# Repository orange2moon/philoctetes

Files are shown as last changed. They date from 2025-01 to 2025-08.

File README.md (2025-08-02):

# Philoctetes Keyboard

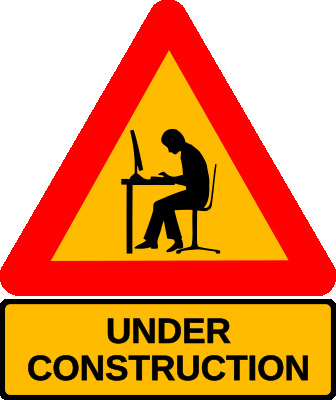
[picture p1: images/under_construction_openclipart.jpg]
Under Construction


## About this project

I have worked on this project for about 3 months. It is quite enjoyable, but also time consuming. I made two working keyboards, one bluetooth and one wireless. The feel of the layout is fantastic! Even if my keyboards are working, it's not ready for other people to build. I hope to have time to continue this project, but I can't make promises to anyone. I am sharing this repository for people who might be curious, and to give ideas so as to inspire people to make awesome keyboards.

__Design goals__  
In [congnitive load theory](https://practicalpie.com/cognitive-load-theory/) there are three processes. These are the intrinsic, the extrinsic, and the germane. The effort put into typing on a keyboard is purely extrinsic. So one day I had an idea, "could I reduce the extrinsic load of typing on a computer by changing my keyboard?". I think the answer is yes. As a result of this idea, my design goals gravitated toward 42 keys that are arranged to match my hand and the movements of my fingers.

This keyboard turned into a very expensive build. It is probably one of the most expensive split keyboards you can build. In addition I only considered the shape and size of my own hand when designing it. Please don't build it.

## Other Projects to Check Out

The [Totem](https://github.com/GEIGEIGEIST/TOTEM) keyboard. The Totem was the inspiration for this keyboard. I have huge respect for the creator of this project. The creator really put a lot of effort into making a great finished project.

I created this project with a different design goal in mind. The design goals of the Totem seem to be a portable and relativly low cost keyboard. In contrast, my design goals are to fit perfectly my own hand.

In addition, a big thanks to the [EIGA](https://www.youtube.com/@EIGAtech) youtube channel. Without their channel I would not have learned about the Totem and other split keyboards.

## To Do

__Case__  
[x] Add a case mount point to the far outside.  
[x] Add more space for the oled (the oled is not centered and it hits the lip holding the cover). Moving the oled mount half a mm towards the edge should help.  
[x] Add more space for the microcontroller (about 1mm on the inner side should do).  
[x] Add a curve for the TRRS conector.  

__PCB Both Sides__  
[x] fix the annotations  
[] change the footprints from sod-323 to sod-123.  
    - The Kicad library footprints look too small for hand soldering.  
[] Update the footprints in the PCB builder.  
[] Redo diode placement  
[] Redo routing  
[] Improve the silkscreen placements.  
[x] Improve the placement of the oled display.  
[x] Add a case mount point to the far outside.  
[x] Add a pull down resistor to the right side.  
[x] Remove the extra diode on the left side.  
[x] Panelize the keyboard.  
[x] Check the column and row labels and makes sure they match.  
[x] Check the oled and nice!view pinouts.  
  
__Project In General__  
[] Create a bill of materials  
[] Create a build guide  
[] Test latest PCB  
  
## Case  
  
The case uses a tenting system that I have used for a year. It's not perfect, but every-time I think of switching to a different design I can't find justification. The advantage of my tenting system is that it is very stable and very adjustable. My tenting system is not portable, meaning it will probably bet messed up if you put it in a bag and ride the subway (been there, done that).  
  
The case was designed using onshape and you can find a link to it [here](https://cad.onshape.com/documents/5c5e04ae1784123d6189c14c/w/86f29d74e9109abb974cb649/e/b3c51a35815c88e0a251e0eb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)  

## Images
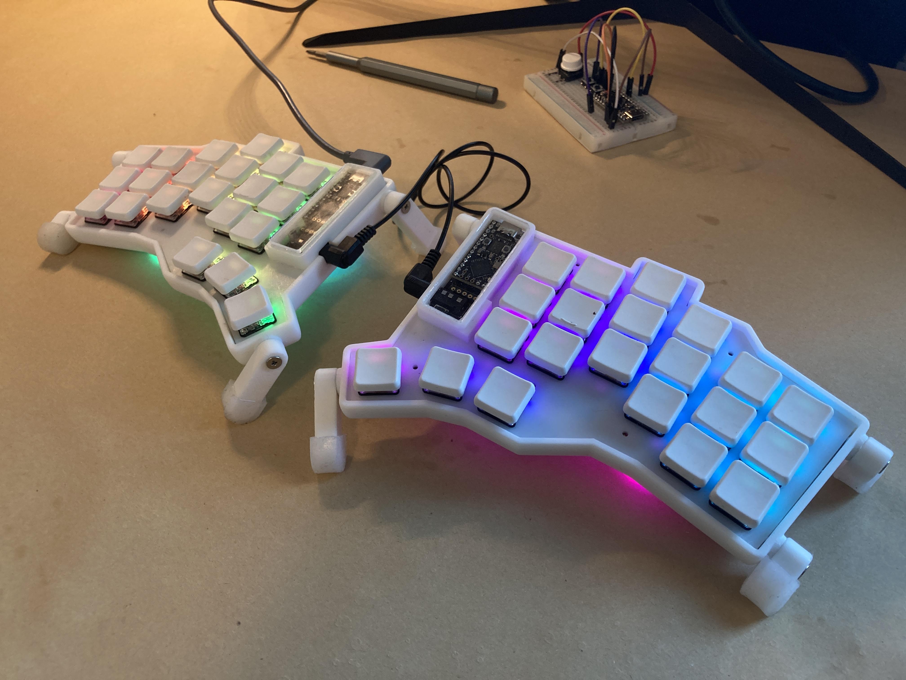
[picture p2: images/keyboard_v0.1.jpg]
Keyboard Version 0.1


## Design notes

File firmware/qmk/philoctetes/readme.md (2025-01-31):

# philoctetes

philoctetes

*A short description of the keyboard/project*

* Keyboard Maintainer: [orange2moon](https://github.com/orange2moon)
* Hardware Supported: *The PCBs, controllers supported*
* Hardware Availability: *Links to where you can find this hardware*

Make example for this keyboard (after setting up your build environment):

    make philoctetes:default

Flashing example for this keyboard:

    make philoctetes:default:flash

See the [build environment setup](https://docs.qmk.fm/#/getting_started_build_tools) and the [make instructions](https://docs.qmk.fm/#/getting_started_make_guide) for more information. Brand new to QMK? Start with our [Complete Newbs Guide](https://docs.qmk.fm/#/newbs).

## Bootloader

Enter the bootloader in 3 ways:

* **Bootmagic reset**: Hold down the key at (0,0) in the matrix (usually the top left key or Escape) and plug in the keyboard
* **Physical reset button**: Briefly press the button on the back of the PCB - some may have pads you must short instead
* **Keycode in layout**: Press the key mapped to `QK_BOOT` if it is available

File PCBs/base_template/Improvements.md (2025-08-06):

# Improvements

## Most important thing, ergonomics
- [x] adjust the ring finger column
    - It needs to come up a little
- [x] adjust the pinky finger column
    - the outer column needs to come up a little
    - the two pinky columns were moved outward a little

middle -> ring vertical space = 7.8 mm or 7.9 

## Mechanical improvements
- Change the footprints of the diodes
- [x] adjust the spacing of individual keys
    - The center is the middle finger, everything else moves around it

- Make room for a bigger battery
    - I could make a cutout under the mcu, this would give more
    clearance for a battery, also moving the display mount down would
    help a lot

## Things I wouldn't change
- The capacitors are great
    - add a bigger one, or two of the electrolytic capacitors, or one
    big through hole electrolytic and bend the wires over so it sits
    horizontally 

What is the spacing between keys vertically?
According to the corne project... it looks to be 19.05 mm 
This seems correct. The distance in my build was 18.13 and it seemed to
be about 1 mm or more too close.

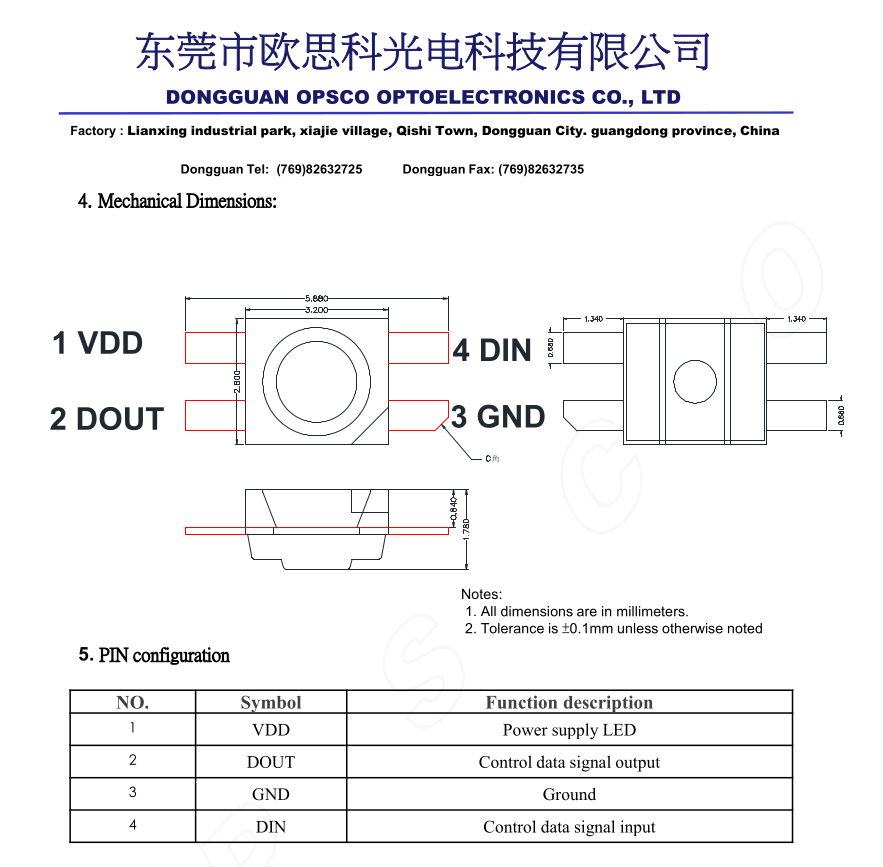
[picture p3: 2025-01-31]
bill_of_materials/data_sheet_ref/SK6812MINI-E_pinout.png

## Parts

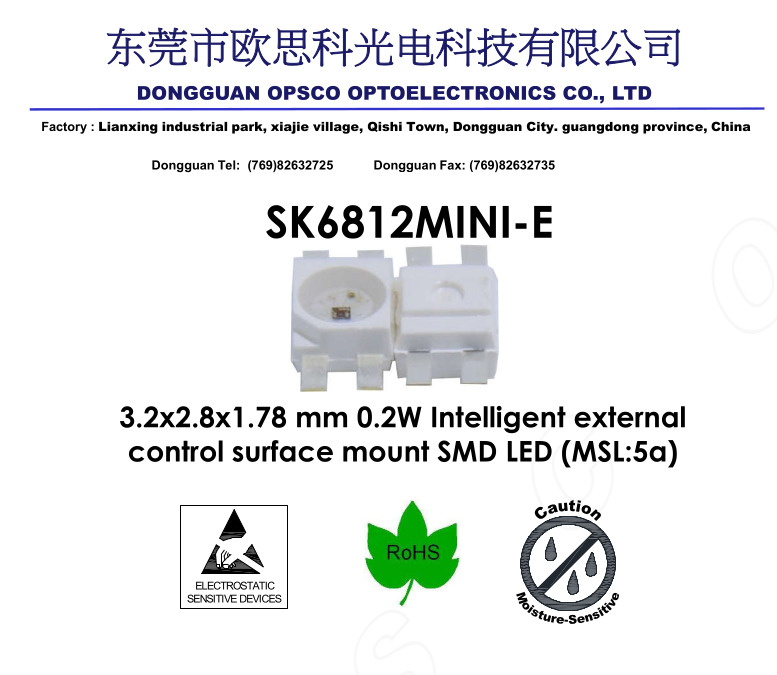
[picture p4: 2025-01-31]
bill_of_materials/data_sheet_ref/SK6812MINI-E.jpg

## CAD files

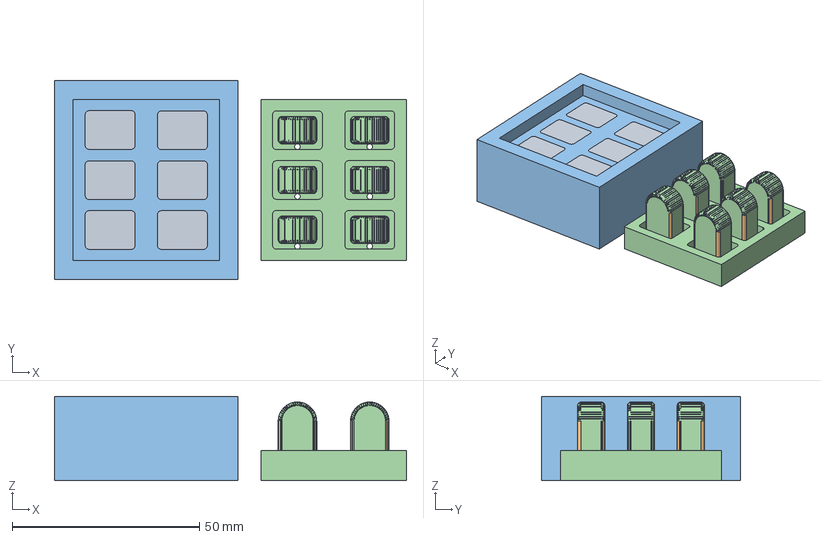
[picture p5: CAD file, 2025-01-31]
extras/silicone_mold_for_endcaps.FCStd
94.0 x 53.0 x 22.5 mm
base
mold_top
mold_bottom
mold_top (Meshed)001

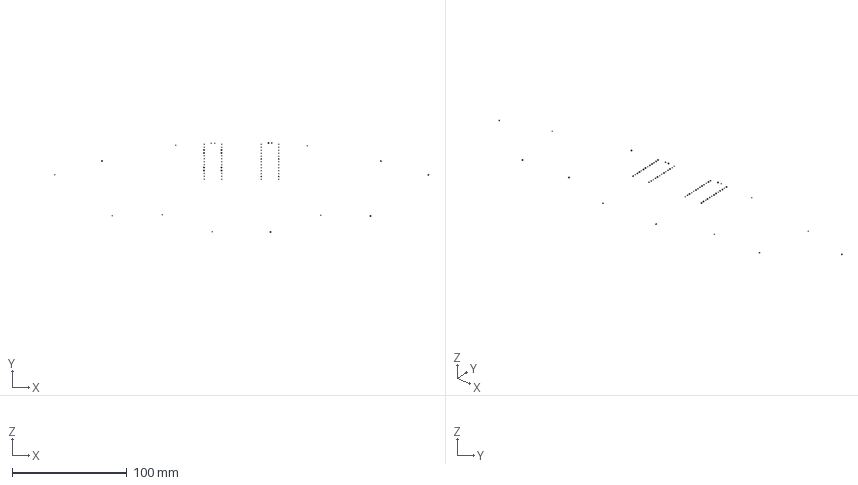
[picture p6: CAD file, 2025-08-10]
PCBs/base_template/layout/pcb_edges/pcb_edges_v3.FCStd
325.8 x 77.9 x 0 mm
circle714
circle715
circle716
circle717
circle718
circle719
circle720
circle721
circle722
circle723
circle724
circle725
circle726
circle727
circle728
circle729
circle730
circle731
circle732
circle733
circle734
circle735
circle736
circle737
circle738
circle739
circle740
circle747
circle760
circle761
circle762
circle763
circle778
circle779
circle816
circle825
circle838
circle839
circle869
circle870
circle871
circle872
circle879
circle880
circle881
circle882
circle883
circle884
circle885
circle886
circle887
circle888
circle889
circle890
circle891
circle892
circle893
circle894
circle895
circle896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

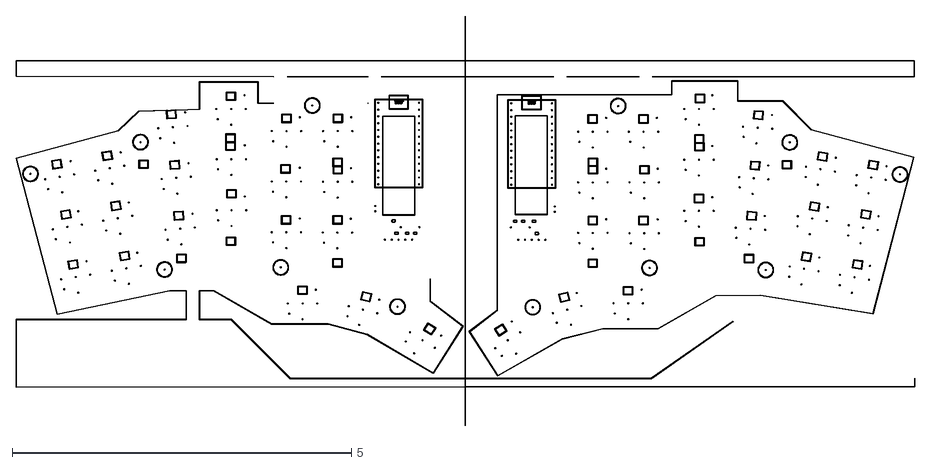
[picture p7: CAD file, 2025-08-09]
PCBs/base_template/layout/philoctetes-Edge_Cuts.dxf
13.2 x 6.03

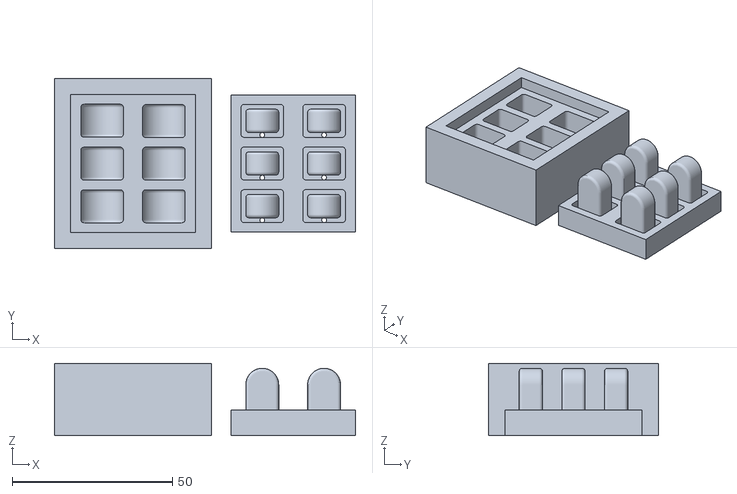
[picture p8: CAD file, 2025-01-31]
releases/V0.1/case/endcap_v3_all.stl
93.9 x 53.0 x 22.5

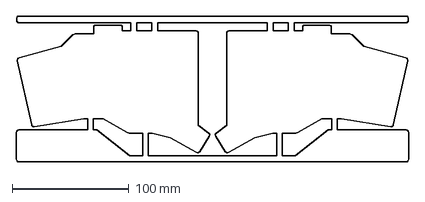
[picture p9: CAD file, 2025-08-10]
PCBs/base_template/layout/pcb_edges/pcb_edges_v3-BodySketch675.dxf
336.6 x 124.8 mm

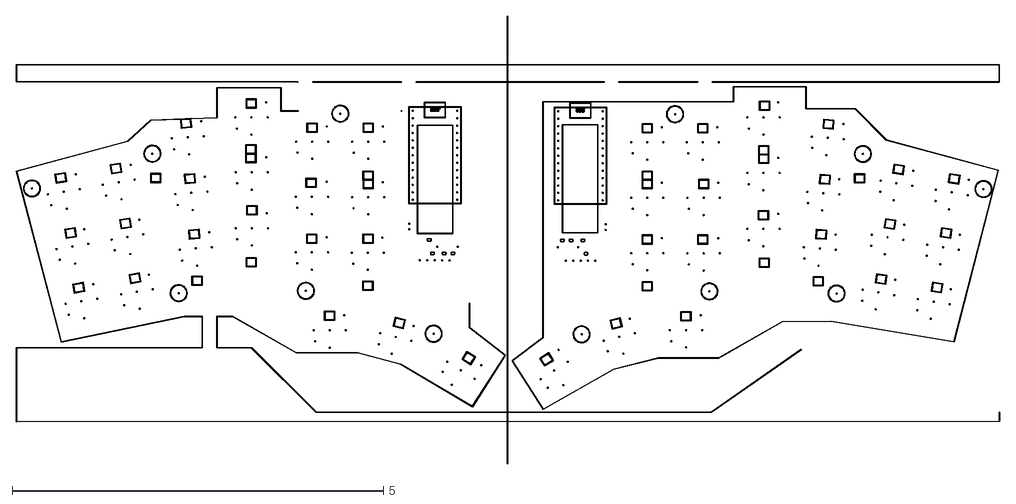
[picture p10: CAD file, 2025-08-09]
PCBs/base_template/layout/philoctetes-User_Comments.dxf
13.2 x 6.03

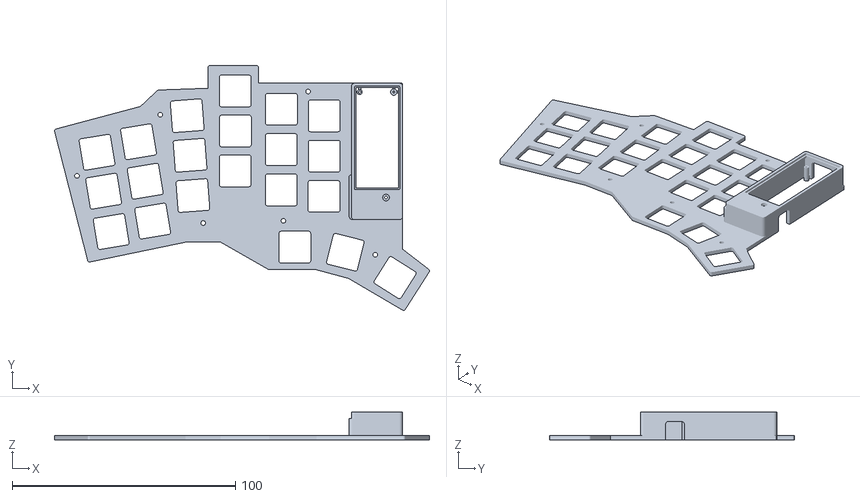
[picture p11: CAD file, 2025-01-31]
releases/V0.1/case/philoctetes_LEFT_top.stl
168.0 x 109.7 x 12.4

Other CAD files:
PCBs/base_template/edge_cuts/edge_cuts.FCStd
releases/V0.1/case/philoctetes_RIGHT_top.stl

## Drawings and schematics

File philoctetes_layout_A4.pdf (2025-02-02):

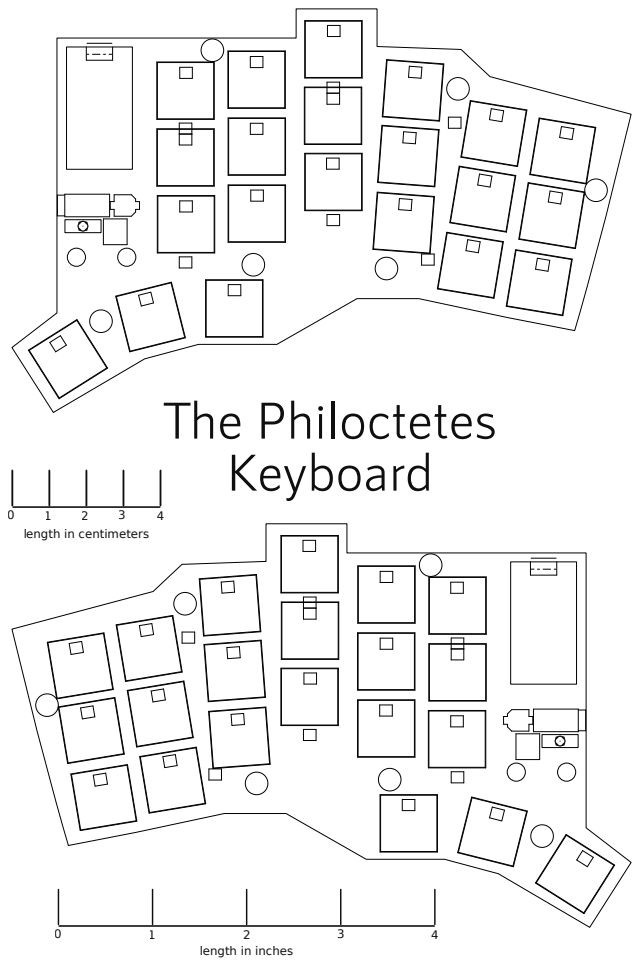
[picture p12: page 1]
The Philoctetes Keyboard

length in centimeters

length in inches

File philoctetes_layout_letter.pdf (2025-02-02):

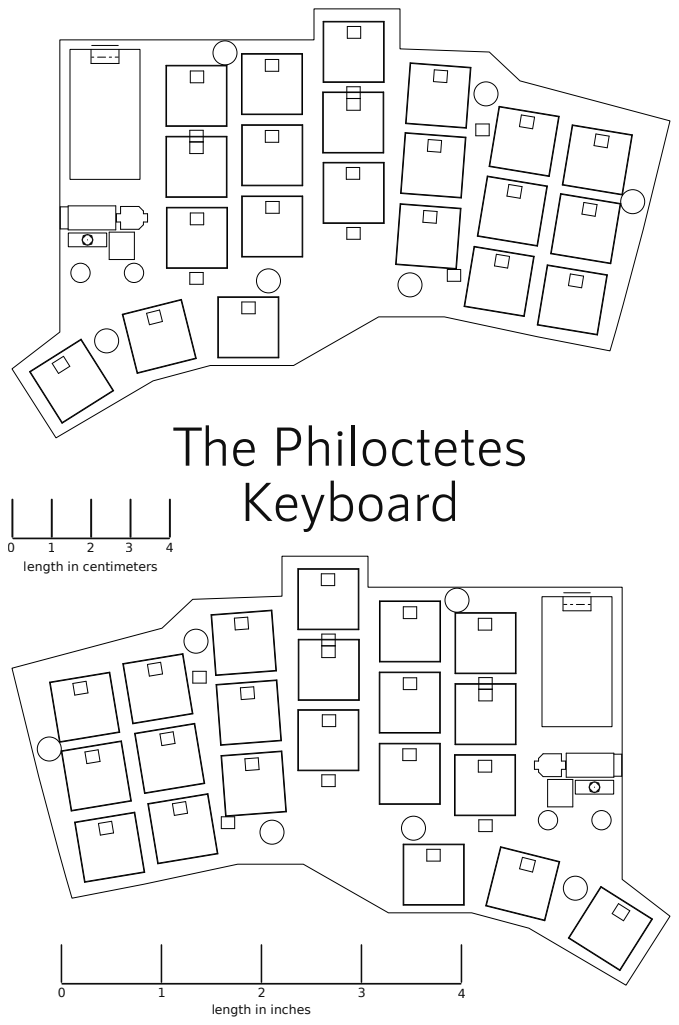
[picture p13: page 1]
The Philoctetes Keyboard

length in centimeters

length in inches

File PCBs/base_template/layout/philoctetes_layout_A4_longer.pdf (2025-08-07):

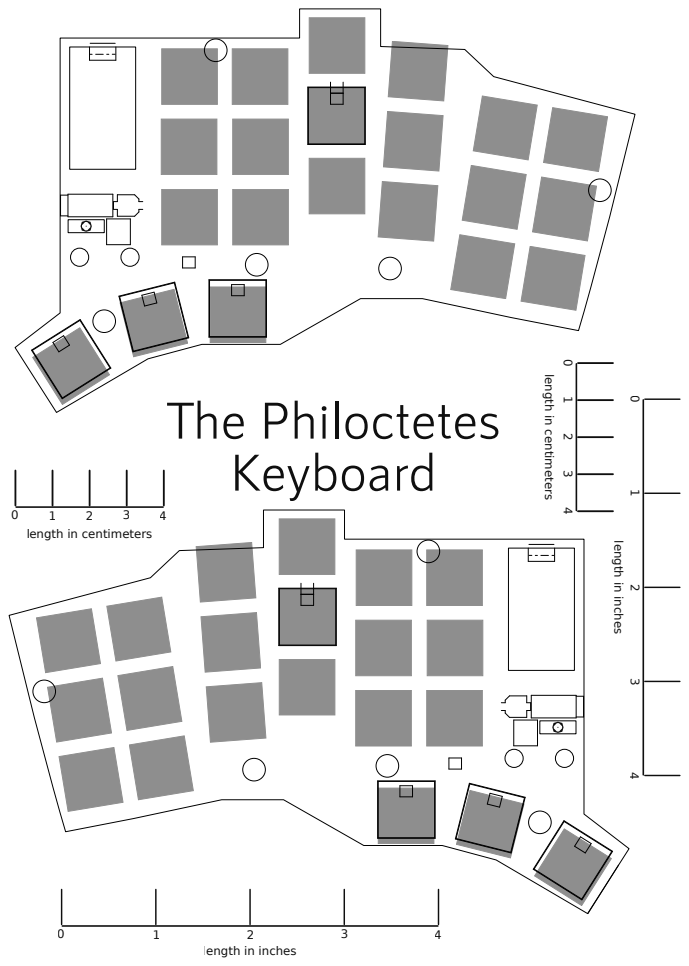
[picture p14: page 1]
The Philoctetes Keyboard

length in centimeters

length in inches

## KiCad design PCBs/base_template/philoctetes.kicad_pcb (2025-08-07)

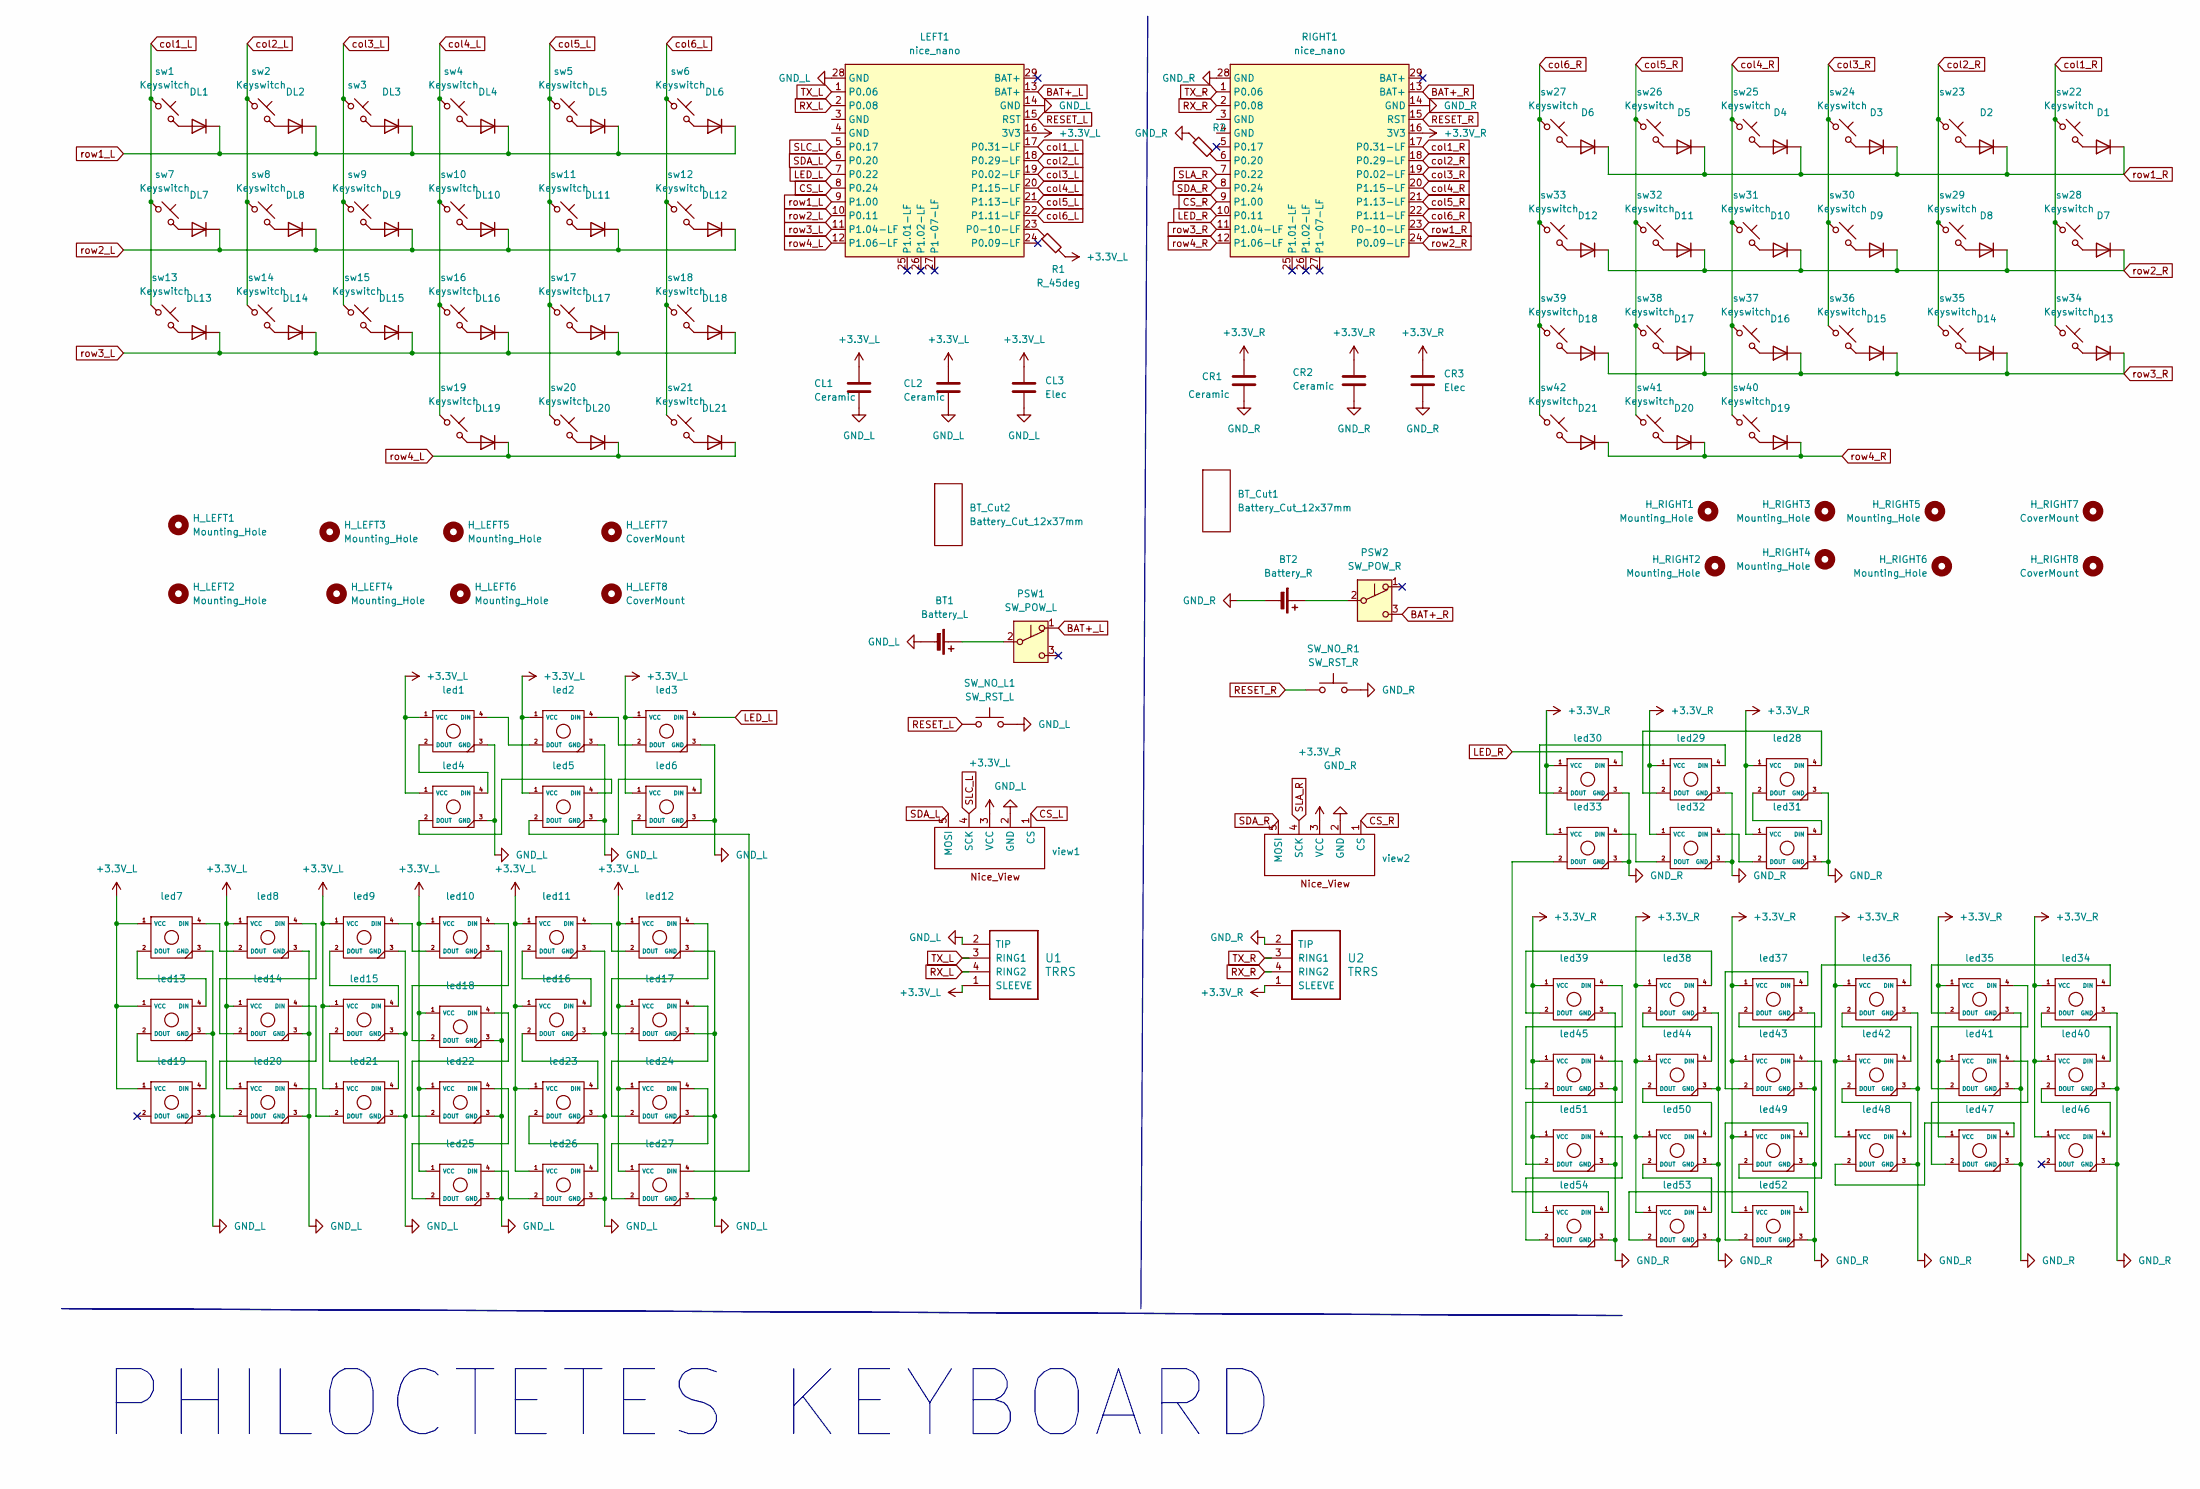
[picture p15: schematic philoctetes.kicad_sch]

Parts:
BT1: Battery_L; JST_GH_SM02B-GHS-TB_1x02-1MP_P1.25mm_Horizontal
BT2: Battery_R; JST_GH_SM02B-GHS-TB_1x02-1MP_P1.25mm_Horizontal
BT_Cut1, BT_Cut2: Battery_Cut_12x37mm
CL1, CL2: Ceramic; C_1206_3216Metric_Pad1.33x1.80mm_HandSolder
CL3: Elec; CP_Radial_D5.0mm_P2.00mm
CR1, CR2: Ceramic; C_1206_3216Metric_Pad1.33x1.80mm_HandSolder
CR3: Elec; CP_Radial_D5.0mm_P2.00mm
D1, D2, D3, D4, D5, D6, D7, D8, D9, D10, D11, D12, D13, D14, D15, D16, D17, D18, D19, D20, D21: 1N4148W; D_SOD-123F
DL1, DL2, DL3, DL4, DL5, DL6, DL7, DL8, DL9, DL10, DL11, DL12, DL13, DL14, DL15, DL16, DL17, DL18, DL19, DL20, DL21: 1N4148W; D_SOD-123F
H_LEFT1, H_LEFT2, H_LEFT3, H_LEFT4, H_LEFT5, H_LEFT6: Mounting_Hole; MountingHole_3.2mm_M3_DIN965
H_LEFT7, H_LEFT8: CoverMount; MountingHole_2.2mm_M2_Pad
H_RIGHT1, H_RIGHT2, H_RIGHT3, H_RIGHT4, H_RIGHT5, H_RIGHT6: Mounting_Hole; MountingHole_3.2mm_M3_DIN965
H_RIGHT7, H_RIGHT8: CoverMount; MountingHole_2.2mm_M2_Pad
LEFT1: nice_nano; nice_nano_AH_USBup
PSW1: SW_POW_L; MSK12C02
PSW2: SW_POW_R; MSK12C02
R1, R2: R_45deg; R_0805_2012Metric
RIGHT1: nice_nano; nice_nano_AH_USBup
SW_NO_L1: SW_RST_L; SW_RST
SW_NO_R1: SW_RST_R; SW_RST
U1, U2: TRRS; TRRS_PJ-320A
led1, led2, led3, led4, led5, led6, led28, led29, led30, led31, led32, led33: LED_SK6812MINI-E_faceup
led7, led8, led9, led10, led11, led12, led13, led14, led15, led16, led17, led18, led19, led20, led21, led22, led23, led24, led25, led26, led27, led34, led35, led36, led37, led38, led39, led40, led41, led42, led43, led44, led45, led46, led47, led48, led49, led50, led51, led52, led53, led54: LED_SK6812MINI-E_facedown
sw1, sw2, sw3, sw4, sw5, sw6, sw7, sw8, sw9, sw10, sw11, sw12, sw13, sw14, sw15, sw16, sw17, sw18, sw19, sw20, sw21, sw22, sw23, sw24, sw25, sw26, sw27, sw28, sw29, sw30, sw31, sw32, sw33, sw34, sw35, sw36, sw37, sw38, sw39, sw40, sw41, sw42: Keyswitch; Hotswap_Choc_V1V2_1.00u
view1, view2: nice_view

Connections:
+3.3V_L: CL1.1, CL2.1, CL3.1, LEFT1.16 (3V3), R1.2, U1.1 (SLEEVE), led1.1 (VCC), led2.1 (VCC), led3.1 (VCC), led4.1 (VCC), led5.1 (VCC), led6.1 (VCC), led7.1 (VCC), led8.1 (VCC), led9.1 (VCC), led10.1 (VCC), led11.1 (VCC), led12.1 (VCC), led13.1 (VCC), led14.1 (VCC), led15.1 (VCC), led16.1 (VCC), led17.1 (VCC), led18.1 (VCC), led19.1 (VCC), led20.1 (VCC), led21.1 (VCC), led22.1 (VCC), led23.1 (VCC), led24.1 (VCC), led25.1 (VCC), led26.1 (VCC), led27.1 (VCC), view1.3 (VCC)
+3.3V_R: CR1.1, CR2.1, CR3.1, RIGHT1.16 (3V3), U2.1 (SLEEVE), led28.1 (VCC), led29.1 (VCC), led30.1 (VCC), led31.1 (VCC), led32.1 (VCC), led33.1 (VCC), led34.1 (VCC), led35.1 (VCC), led36.1 (VCC), led37.1 (VCC), led38.1 (VCC), led39.1 (VCC), led40.1 (VCC), led41.1 (VCC), led42.1 (VCC), led43.1 (VCC), led44.1 (VCC), led45.1 (VCC), led46.1 (VCC), led47.1 (VCC), led48.1 (VCC), led49.1 (VCC), led50.1 (VCC), led51.1 (VCC), led52.1 (VCC), led53.1 (VCC), led54.1 (VCC), view2.3 (VCC)
BAT+_L: LEFT1.13 (BAT+), PSW1.1 (A)
BAT+_R: PSW2.3 (C), RIGHT1.13 (BAT+)
CS_L: LEFT1.8 (P0.24), view1.1 (CS)
CS_R: RIGHT1.9 (P1.00), view2.1 (CS)
GND_L: BT1.2 (-), CL1.2, CL2.2, CL3.2, LEFT1.14 (GND), LEFT1.28 (GND), SW_NO_L1.2, U1.2 (TIP), led1.3 (GND), led2.3 (GND), led3.3 (GND), led4.3 (GND), led5.3 (GND), led6.3 (GND), led7.3 (GND), led8.3 (GND), led9.3 (GND), led10.3 (GND), led11.3 (GND), led12.3 (GND), led13.3 (GND), led14.3 (GND), led15.3 (GND), led16.3 (GND), led17.3 (GND), led18.3 (GND), led19.3 (GND), led20.3 (GND), led21.3 (GND), led22.3 (GND), led23.3 (GND), led24.3 (GND), led25.3 (GND), led26.3 (GND), led27.3 (GND), view1.2 (GND)
GND_R: BT2.2 (-), CR1.2, CR2.2, CR3.2, R2.2, RIGHT1.14 (GND), RIGHT1.28 (GND), SW_NO_R1.2, U2.2 (TIP), led28.3 (GND), led29.3 (GND), led30.3 (GND), led31.3 (GND), led32.3 (GND), led33.3 (GND), led34.3 (GND), led35.3 (GND), led36.3 (GND), led37.3 (GND), led38.3 (GND), led39.3 (GND), led40.3 (GND), led41.3 (GND), led42.3 (GND), led43.3 (GND), led44.3 (GND), led45.3 (GND), led46.3 (GND), led47.3 (GND), led48.3 (GND), led49.3 (GND), led50.3 (GND), led51.3 (GND), led52.3 (GND), led53.3 (GND), led54.3 (GND), view2.2 (GND)
LED_L: LEFT1.7 (P0.22), led3.4 (DIN)
LED_R: RIGHT1.10 (P0.11), led30.4 (DIN)
unnamed: BT1.1 (+), PSW1.2 (B)
unnamed: BT2.1 (+), PSW2.2 (B)
unnamed: D1.2 (A), sw22.2
unnamed: D2.2 (A), sw23.2
unnamed: D3.2 (A), sw24.2
unnamed: D4.2 (A), sw25.2
unnamed: D5.2 (A), sw26.2
unnamed: D6.2 (A), sw27.2
unnamed: D7.2 (A), sw28.2
unnamed: D8.2 (A), sw29.2
unnamed: D9.2 (A), sw30.2
unnamed: D10.2 (A), sw31.2
unnamed: D11.2 (A), sw32.2
unnamed: D12.2 (A), sw33.2
unnamed: D13.2 (A), sw34.2
unnamed: D14.2 (A), sw35.2
unnamed: D15.2 (A), sw36.2
unnamed: D16.2 (A), sw37.2
unnamed: D17.2 (A), sw38.2
unnamed: D18.2 (A), sw39.2
unnamed: D19.2 (A), sw40.2
unnamed: D20.2 (A), sw41.2
unnamed: D21.2 (A), sw42.2
unnamed: DL1.2 (A), sw1.2
unnamed: DL2.2 (A), sw2.2
unnamed: DL3.2 (A), sw3.2
unnamed: DL4.2 (A), sw4.2
unnamed: DL5.2 (A), sw5.2
unnamed: DL6.2 (A), sw6.2
unnamed: DL7.2 (A), sw7.2
unnamed: DL8.2 (A), sw8.2
unnamed: DL9.2 (A), sw9.2
unnamed: DL10.2 (A), sw10.2
unnamed: DL11.2 (A), sw11.2
unnamed: DL12.2 (A), sw12.2
unnamed: DL13.2 (A), sw13.2
unnamed: DL14.2 (A), sw14.2
unnamed: DL15.2 (A), sw15.2
unnamed: DL16.2 (A), sw16.2
unnamed: DL17.2 (A), sw17.2
unnamed: DL18.2 (A), sw18.2
unnamed: DL19.2 (A), sw19.2
unnamed: DL20.2 (A), sw20.2
unnamed: DL21.2 (A), sw21.2
unnamed: LEFT1.23 (P0-10-LF), R1.1
unnamed: R2.1, RIGHT1.6 (P0.20)
unnamed: led1.4 (DIN), led2.2 (DOUT)
unnamed: led1.2 (DOUT), led4.4 (DIN)
unnamed: led2.4 (DIN), led3.2 (DOUT)
unnamed: led4.2 (DOUT), led5.4 (DIN)
unnamed: led5.2 (DOUT), led6.4 (DIN)
unnamed: led7.4 (DIN), led8.2 (DOUT)
unnamed: led10.4 (DIN), led18.2 (DOUT)
unnamed: led9.4 (DIN), led10.2 (DOUT)
unnamed: led11.4 (DIN), led12.2 (DOUT)
unnamed: led11.2 (DOUT), led16.4 (DIN)
unnamed: led12.4 (DIN), led17.2 (DOUT)
unnamed: led7.2 (DOUT), led13.4 (DIN)
unnamed: led13.2 (DOUT), led19.4 (DIN)
unnamed: led14.4 (DIN), led20.2 (DOUT)
unnamed: led8.4 (DIN), led14.2 (DOUT)
unnamed: led9.2 (DOUT), led15.4 (DIN)
unnamed: led15.2 (DOUT), led21.4 (DIN)
unnamed: led16.2 (DOUT), led23.4 (DIN)
unnamed: led17.4 (DIN), led24.2 (DOUT)
unnamed: led18.4 (DIN), led22.2 (DOUT)
unnamed: led20.4 (DIN), led21.2 (DOUT)
unnamed: led22.4 (DIN), led25.2 (DOUT)
unnamed: led23.2 (DOUT), led26.4 (DIN)
unnamed: led24.4 (DIN), led27.2 (DOUT)
unnamed: led25.4 (DIN), led26.2 (DOUT)
unnamed: led6.2 (DOUT), led27.4 (DIN)
unnamed: led28.4 (DIN), led29.2 (DOUT)
unnamed: led28.2 (DOUT), led31.4 (DIN)
unnamed: led29.4 (DIN), led30.2 (DOUT)
unnamed: led31.2 (DOUT), led32.4 (DIN)
unnamed: led32.2 (DOUT), led33.4 (DIN)
unnamed: led33.2 (DOUT), led54.4 (DIN)
unnamed: led34.4 (DIN), led35.2 (DOUT)
unnamed: led34.2 (DOUT), led40.4 (DIN)
unnamed: led35.4 (DIN), led41.2 (DOUT)
unnamed: led36.4 (DIN), led37.2 (DOUT)
unnamed: led36.2 (DOUT), led42.4 (DIN)
unnamed: led37.4 (DIN), led43.2 (DOUT)
unnamed: led38.4 (DIN), led39.2 (DOUT)
unnamed: led38.2 (DOUT), led44.4 (DIN)
unnamed: led39.4 (DIN), led45.2 (DOUT)
unnamed: led40.2 (DOUT), led46.4 (DIN)
unnamed: led41.4 (DIN), led47.2 (DOUT)
unnamed: led42.2 (DOUT), led48.4 (DIN)
unnamed: led43.4 (DIN), led49.2 (DOUT)
unnamed: led44.2 (DOUT), led50.4 (DIN)
unnamed: led45.4 (DIN), led51.2 (DOUT)
unnamed: led47.4 (DIN), led48.2 (DOUT)
unnamed: led49.4 (DIN), led52.2 (DOUT)
unnamed: led50.2 (DOUT), led53.4 (DIN)
unnamed: led51.4 (DIN), led54.2 (DOUT)
unnamed: led52.4 (DIN), led53.2 (DOUT)
RESET_L: LEFT1.15 (RST), SW_NO_L1.1
RESET_R: RIGHT1.15 (RST), SW_NO_R1.1
RX_L: LEFT1.2 (P0.08), U1.4 (RING2)
RX_R: RIGHT1.2 (P0.08), U2.4 (RING2)
SDA_L: LEFT1.6 (P0.20), view1.5 (MOSI)
SDA_R: RIGHT1.8 (P0.24), view2.5 (MOSI)
SLA_R: RIGHT1.7 (P0.22), view2.4 (SCK)
SLC_L: LEFT1.5 (P0.17), view1.4 (SCK)
TX_L: LEFT1.1 (P0.06), U1.3 (RING1)
TX_R: RIGHT1.1 (P0.06), U2.3 (RING1)
col1_L: LEFT1.17 (P0.31-LF), sw1.1, sw7.1, sw13.1
col1_R: RIGHT1.17 (P0.31-LF), sw22.1, sw28.1, sw34.1
col2_L: LEFT1.18 (P0.29-LF), sw2.1, sw8.1, sw14.1
col2_R: RIGHT1.18 (P0.29-LF), sw23.1, sw29.1, sw35.1
col3_L: LEFT1.19 (P0.02-LF), sw3.1, sw9.1, sw15.1
col3_R: RIGHT1.19 (P0.02-LF), sw24.1, sw30.1, sw36.1
col4_L: LEFT1.20 (P1.15-LF), sw4.1, sw10.1, sw16.1, sw19.1
col4_R: RIGHT1.20 (P1.15-LF), sw25.1, sw31.1, sw37.1, sw40.1
col5_L: LEFT1.21 (P1.13-LF), sw5.1, sw11.1, sw17.1, sw20.1
col5_R: RIGHT1.21 (P1.13-LF), sw26.1, sw32.1, sw38.1, sw41.1
col6_L: LEFT1.22 (P1.11-LF), sw6.1, sw12.1, sw18.1, sw21.1
col6_R: RIGHT1.22 (P1.11-LF), sw27.1, sw33.1, sw39.1, sw42.1
row1_L: DL1.1 (K), DL2.1 (K), DL3.1 (K), DL4.1 (K), DL5.1 (K), DL6.1 (K), LEFT1.9 (P1.00)
row1_R: D1.1 (K), D2.1 (K), D3.1 (K), D4.1 (K), D5.1 (K), D6.1 (K), RIGHT1.23 (P0-10-LF)
row2_L: DL7.1 (K), DL8.1 (K), DL9.1 (K), DL10.1 (K), DL11.1 (K), DL12.1 (K), LEFT1.10 (P0.11)
row2_R: D7.1 (K), D8.1 (K), D9.1 (K), D10.1 (K), D11.1 (K), D12.1 (K), RIGHT1.24 (P0.09-LF)
row3_L: DL13.1 (K), DL14.1 (K), DL15.1 (K), DL16.1 (K), DL17.1 (K), DL18.1 (K), LEFT1.11 (P1.04-LF)
row3_R: D13.1 (K), D14.1 (K), D15.1 (K), D16.1 (K), D17.1 (K), D18.1 (K), RIGHT1.11 (P1.04-LF)
row4_L: DL19.1 (K), DL20.1 (K), DL21.1 (K), LEFT1.12 (P1.06-LF)
row4_R: D19.1 (K), D20.1 (K), D21.1 (K), RIGHT1.12 (P1.06-LF)

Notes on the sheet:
PHILOCTETES KEYBOARD

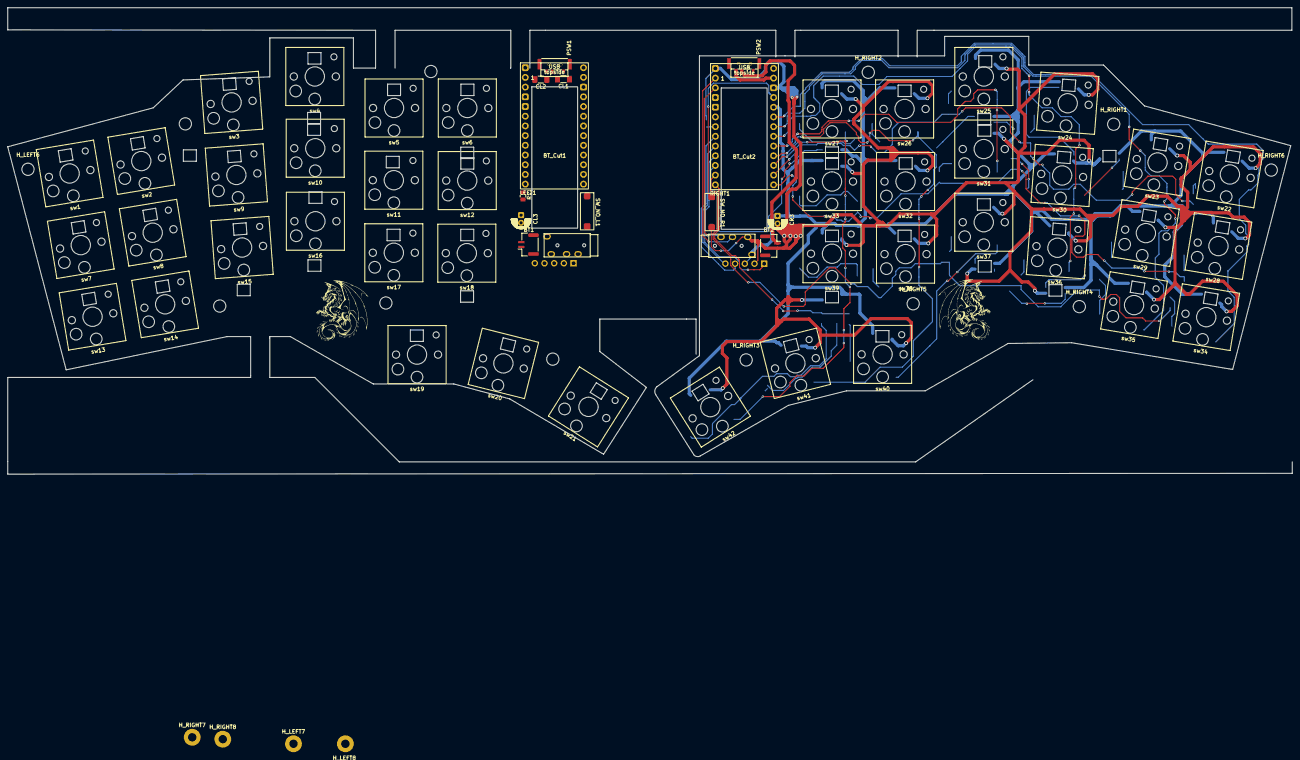
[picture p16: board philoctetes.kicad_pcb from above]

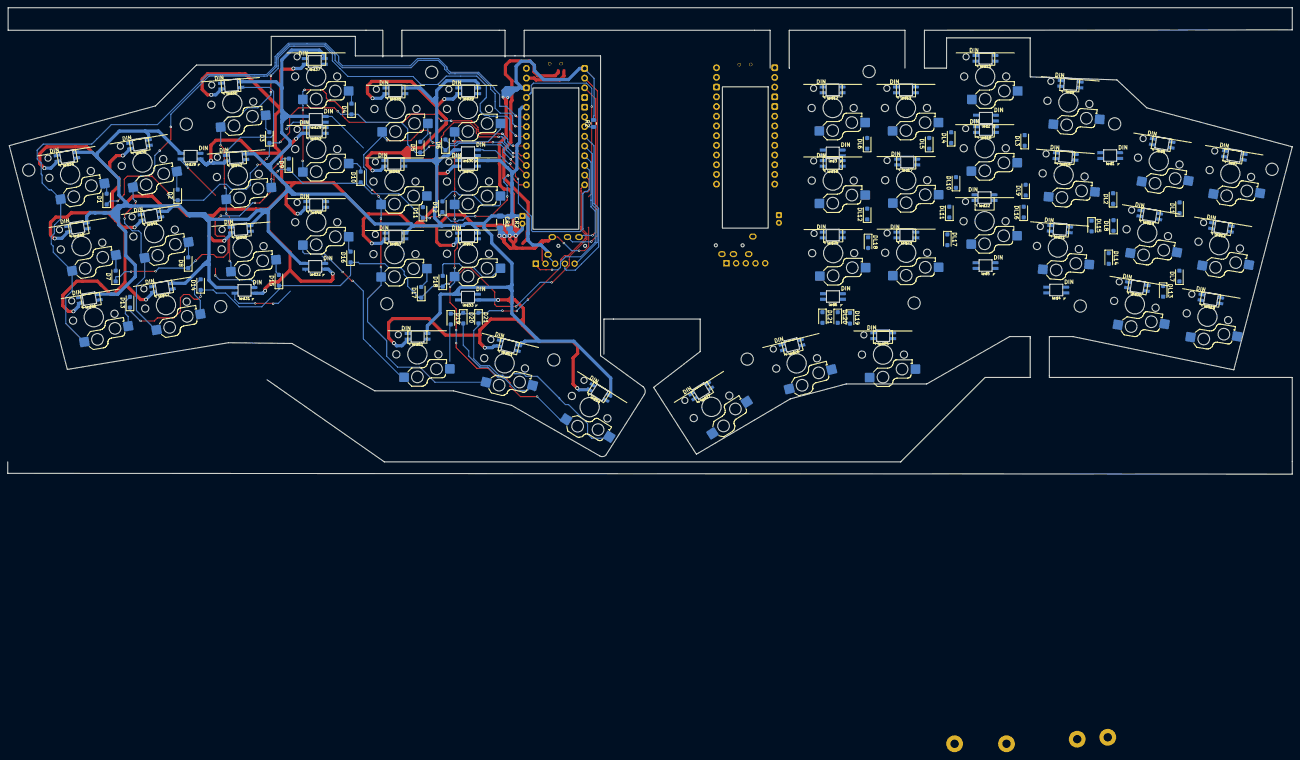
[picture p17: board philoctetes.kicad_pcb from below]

Board: 2 copper layers, 336.3 x 122.1 mm, 176 parts (45 on the bottom side), 138 nets.

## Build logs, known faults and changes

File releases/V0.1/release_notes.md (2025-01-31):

# Release V0.1

## PCB
### Overall Notes

If you add a pull-up resistor (with magnet wire or some other wire), pretty much all features are working. The display was not tested.

The diode footprint is very small making it difficult to build. __SOD-323 diodes are masochistic__. When building this keyboard, __a hot hair station is recommended__. It probably won't work with only a soldering iron.

### Working
+ LED
+ All switches
+ TX and RX
+ Power
+ Battery (in conjunction with a nice!nano V2)

## Not Working
- hadedness detection (can be set manually in firmware or a pull down resistor can be added to the right side.)

### Not tested
- OLED
- Low power display (the kind you'd want to use in a wireless build)

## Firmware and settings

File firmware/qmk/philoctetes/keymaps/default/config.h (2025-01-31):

#pragma once

// This is default
//#define RP2040_FLASH_W25Q080

// HANDEDNESS OPTIONS
#define SPLIT_HAND_PIN GP23
//#define MASTER_LEFT

// DEBUG OPTIONS
//#define DEBUG_MATRIX_SCAN_RATE
//#define DEBUG_SERIAL


//SERIAL OPTIONS
#define SERIAL_USART_TX_PIN GP0
#define SERIAL_USART_RX_PIN GP1
// DATA sync options
// most/all of these are not needed
#define RGBLIGHT_SPLIT
#define RBGLED_SPLIT { 27, 27 }
//#define SPLIT_LAYER_STATE_ENABLE
//#define SPLIT_LED_STATE_ENABLE
//#define SPLIT_MODS_ENABLE
//#define SPLIT_OLED_ENABLE
//#define SPLIT_ACTIVITY_ENABLE

// MY CUSTOM CONFIG KEY SECTION
#define BOTH_SHIFTS_TURNS_ON_CAPS_WORD
#define TAPPING_TERM 190
#define TAPPING_TERM_PER_KEY
#define DYNAMIC_KEYMAP_LAYER_COUNT 6

#define ONESHOT_TAP_TOGGLE 3
#define ONESHOT_TAP_TIMEOUT 10000

// BEGIN mousekey config
// Delay between pressing a movement key
// and cursor movement
#define MOUSEKEY_DELAY 10

// Time between cursor movements in milliseconds
#define MOUSEKEY_INTERVAL    20

// Step size
#define MOUSEKEY_MOVE_DELTA  8 	// Step size

// MAXIMUM cursor speed at which acceleration stops
#define MOUSEKEY_MAX_SPEED 	 10

// Time until maximum cursor speed is reached
#define MOUSEKEY_TIME_TO_MAX 30

// Delay between pressing a wheel key and wheel movement
#define MOUSEKEY_WHEEL_DELAY 10

// Time between wheel movements
#define MOUSEKEY_WHEEL_INTERVAL 80

// Wheel movement step size
#define MOUSEKEY_WHEEL_DELTA 1

// Maximum number of scroll steps per scroll action
#define MOUSEKEY_WHEEL_MAX_SPEED 8

// Time until maximum scroll speed is reached
#define MOUSEKEY_WHEEL_TIME_TO_MAX 40





// BEGIN RGB SECTION
#define RGBLIGHT_LAYERS
#define RGBLIGHT_LAYERS_RETAIN_VAL
//#define RGBLIGHT_KEYPRESSES // reacts to keypresses
//#define RGBLIGHT_KEYRELEASES // reacts to releases
//#define RGBLIGHT_TIMEOUT 300000 // in milliseconds
//#define RGBLIGHT_SLEEP // turn off effects when suspended
//#define RGBLIGHT_LED_PROCESS_LIMIT (RGB_MATRIX_LED_COUNT + 4) / 5 // increases keyboard responsiveness
//#define RGBLIGHT_LED_FLUSH_LIMIT 16 // in ms, 16 ms ~ 60 fps
//#define RGBLIGHT_MAXIMUM_BRIGHTNESS 255 // 200 out of 255
//#define RGBLIGHT_DEFAULT_ON true
//#define RGBLIGHT_DEFAULT_HUE 0
//#define RGBLIGHT_DEFAULT_SAT 255
//#define RGBLIGHT_DEFAULT_VAL RGBLIGHT_LIMIT_VAL
#define RGBLIGHT_DEFAULT_SPD 127
#define RGBLIGHT_DEFAULT_ON true
//#define RGBLIGHT_DEFAULT_FLAGS LED_FLAG_ALL
//#define RGBLIGHT_DISABLE_KEYCODES // disables control of rgb matrix by keycodes (must use code functions to control the feature)
#define RGBLIGHT_HUE_STEP 8
#define RGBLIGHT_SAT_STEP 17
#define RGBLIGHT_VAL_STEP 17
#define RGBLIGHT_SPD_STEP 10




//  BEGIN OLED SECTION
#ifdef OLED_ENABLE
#define OLED_FONT_H "keyboards/crkbd/lib/glcdfont.c"
#define OLED_TRANSPORT i2c
#define OLED_DRIVER ssd1306
#define OLED_BRIGHTNESS 185
#define OLED_UPDATE_INTERVAL 50
//#define SPLIT_OLED_ENABLE

#endif

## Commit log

2025-01-31 repo creation
    [philoctetes.kicad_pcb, philoctetes.kicad_sch]
2025-01-31 basic board setup
    [philoctetes.kicad_sch]
2025-01-31 added case files
    [endcap_v3_all.stl, philoctetes.kicad_sch, philoctetes_LEFT_top.stl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]
2025-01-31 layout pdf for printing
2025-02-01 updates annotations
    [philoctetes.kicad_sch]
2025-08-06 layout right side improvements
    [philoctetes.kicad_pcb, philoctetes.kicad_sch]
2025-08-07 working on routing
    [philoctetes.kicad_pcb]
2025-08-07 routing right half; diodes, power, reset, tx, rx, clk...
2025-08-09 worked on edge cuts, made freecad, mirrored, imported to kicad
    [edge_cuts.FCStd, pcb_edges.FCStd, pcb_edges_v2.FCStd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]
2025-08-10 Finished routing and edge cuts, next up.. check for mistakes.
    [pcb_edges.FCStd, pcb_edges_v2.FCStd, pcb_edges_v3-BodySketch675.dxf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]
2025-08-10 fixed some routing mistakes, added some clearance for tx/rx, added per led 1nf capacitors (needs to place footprints)
    [philoctetes.kicad_sch]
2025-08-12 placed all 1NF capacitors
    [philoctetes.kicad_sch]
2025-08-12 rotary encoder considerations
    [philoctetes.kicad_sch]

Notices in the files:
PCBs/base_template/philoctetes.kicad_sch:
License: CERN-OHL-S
